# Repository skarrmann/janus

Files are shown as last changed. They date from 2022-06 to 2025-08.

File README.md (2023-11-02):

# Janus Keyboard

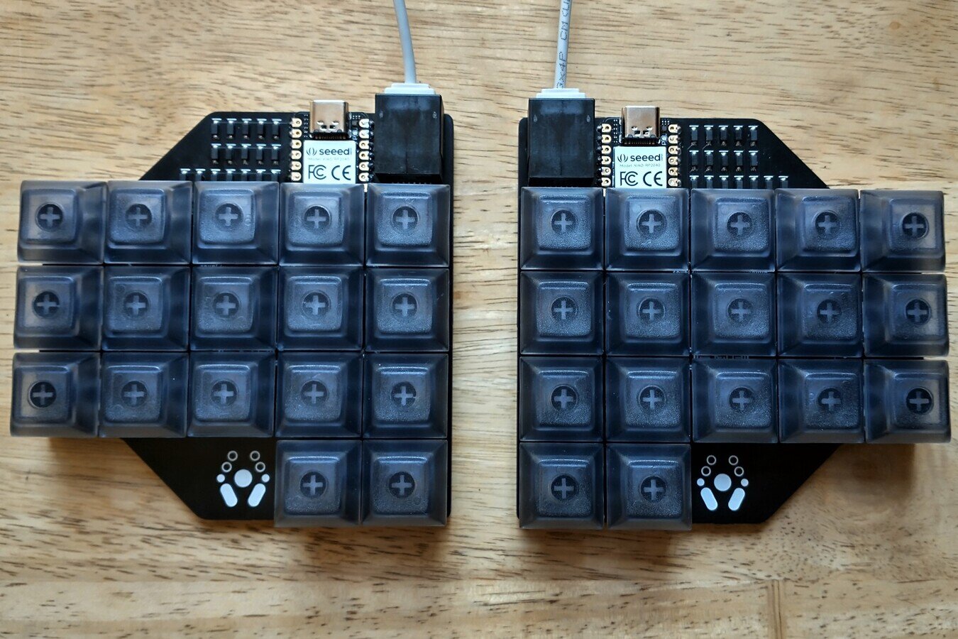
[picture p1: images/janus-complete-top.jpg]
Janus complete build top photo


Janus is a small 34 key split ortholinear keyboard, powered by two Seeed XIAO RP2040 with the keyboards halves connected by an ethernet cable.

The PCB works as both a logical PCB and a bottom plate.

This keyboard is a grid of 1U keys with no special features: no hotswap, no RGB (except those on the XIAO RP2040), no OLED screen, no knobs. It only supports Cherry MX style switches.

## Project structure

* [`gerbers`](gerbers): Gerber files for PCB manufacturing
* [`graphics`](graphics): Source assets for PCB silkscreen
* [`kicad`](kicad): KiCad project files (schematics and PCB designs)
* [`kicad-libraries`](kicad-libraries): KiCad components and footprints
* [`images`](images): Images for project documentation
* [`firmware`](firmware): Firmware files

## PCBs

There is only one PCB design, and 4 copies of this PCB are used to assemble a single keyboard with bottom plates.

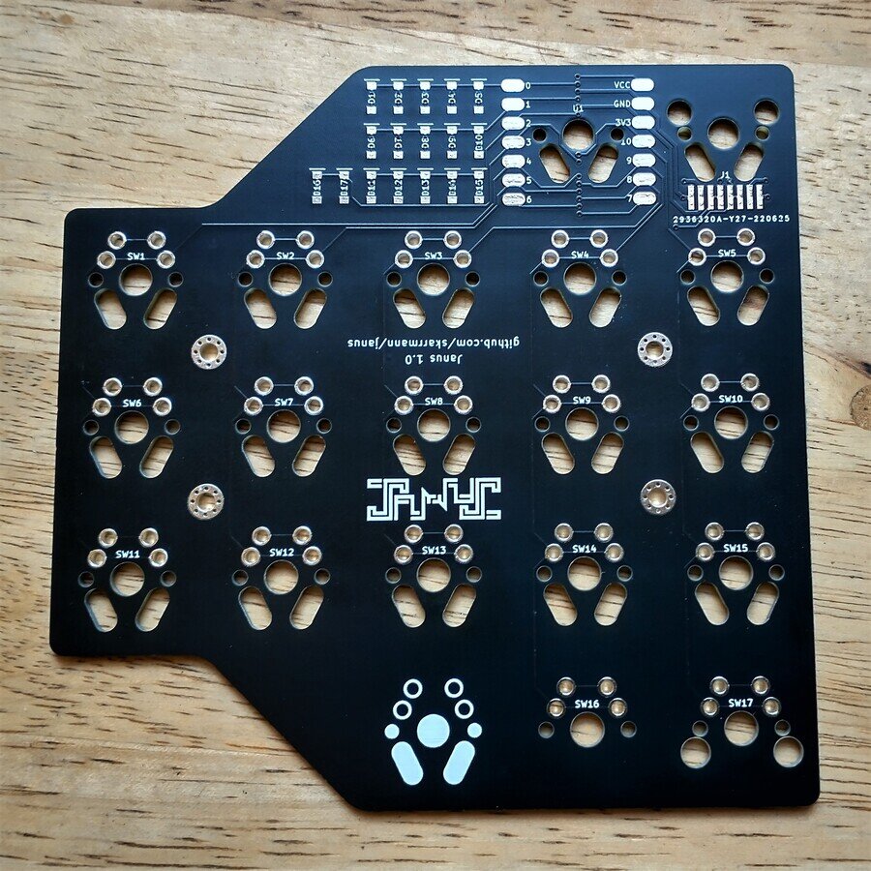
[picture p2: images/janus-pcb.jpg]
Janus one PCB

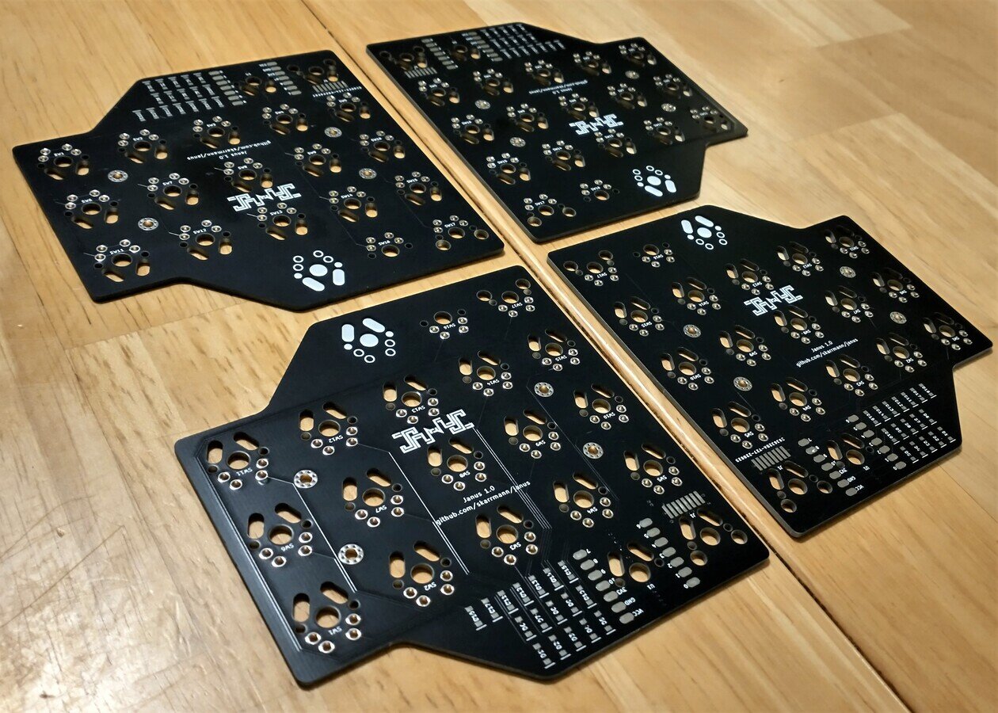
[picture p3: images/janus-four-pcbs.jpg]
Janus four PCBs


The PCB serves as both halves of the split keyboard, as well as bottom plates for those halves.

Flip the board horizontally to get the other keyboard half.

Both keyboard halves have surface-mount solder pads for diodes, microcontroller, and ethernet jack, all on the top side of the PCB.

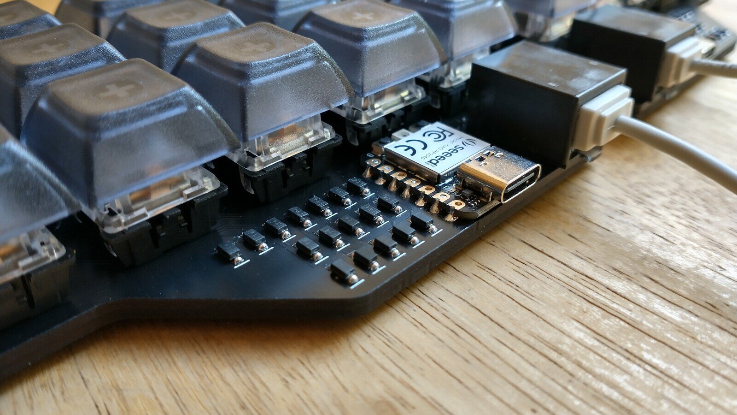
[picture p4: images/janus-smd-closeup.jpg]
Janus SMD components


The PCB is flipped vertically to serve as a bottom plate. The bottom plates are screwed directly to the logical PCB. Note the cutouts on the PCB line up with all the components' through-hole and plastic pins sticking out the bottom of the logical PCB.

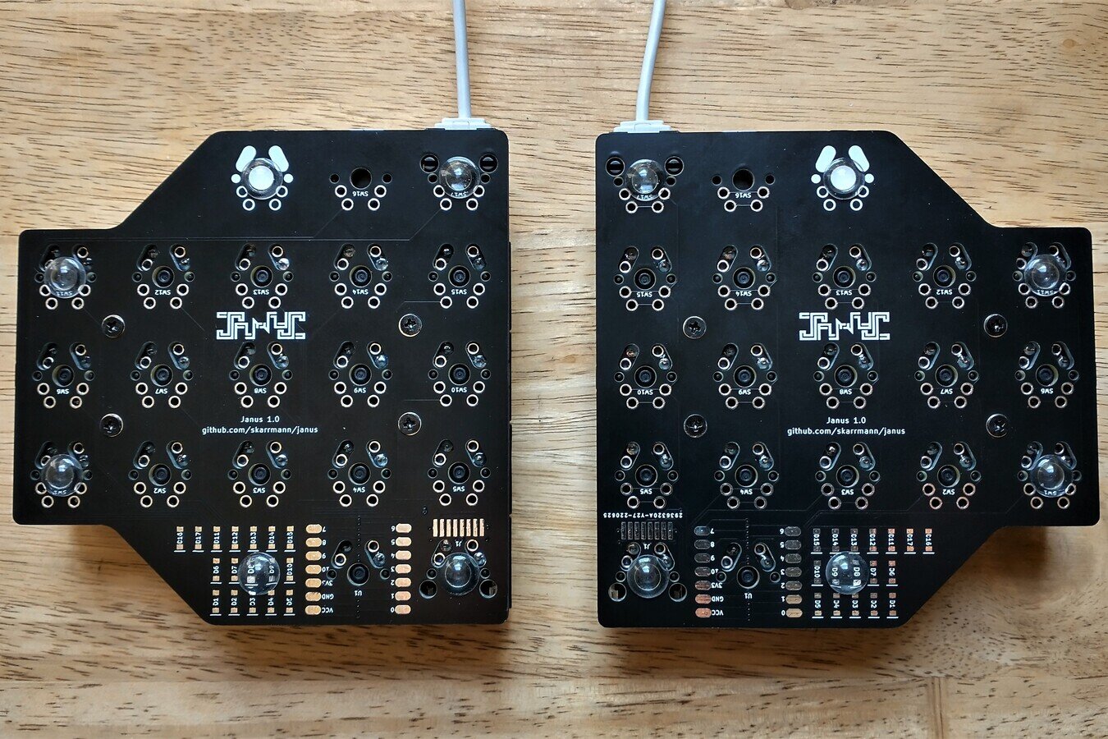
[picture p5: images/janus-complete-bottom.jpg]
Janus complete build bottom photo

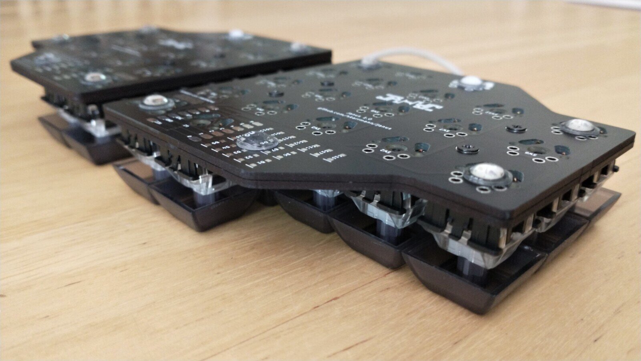
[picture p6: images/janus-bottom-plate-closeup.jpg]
Janus bottom plate closeup


The two halves of the keyboard communicate using full-duplex serial. Note the RX and TX connections are flipped on the top/bottom ethernet jack connections (TX connects to RX and vice-versa).

## Keyboard firmware

* KMK
    * Setup instructions and basic configuration is in this repo: [`firmware/kmk`](firmware/kmk)
* [QMK](https://github.com/qmk/qmk_firmware/tree/master/keyboards/janus)

## Bill of materials

Part | Purpose | Quantity | Notes
---- | ------- | -------- | ---------
PCB  | circuit board | 4 |
Seeed XIAO RP2040 | Microcontroller board | 2 |
Kycon GMX-SMT2-N-88 | connect keyboard halves | 2 | This **exact** connector must be used to fit the board footprint!
1N4148 SOD-123 | Diodes for keyboard row-column matrix | 34 |
Keyswitches |  | 34 | PCB mount (5 pin) switches recommended
Keycaps |  | 34 |
M2 6mm screws | Secure main PCB and plate PCBs | 8 |
M2 nuts | Secure main PCB and plate PCBs | 8 |
2mm tall rubber bumpons | Raise board above desk surface and provide skid resitance | 12 |

You will also need an ethernet patch cable to connect the keyboard halves. Monoprice Micro SlimRun cables are my personal recommendation.

## PCB manufacturing settings

These are the manufacturing settings I used when ordering from JLCPCB:

* **Base Material**: FR4
* **Layers**: 2
* **Dimensions**: (whatever the gerber file specifies)
* **PCB Qty**: 5
* **Different Design**: 1
* **Delivery Format**: Single PCB
* **PCB Thickness**: 1.6
* **PCB Color**: Black
* **Silkscreen**: White
* **Surface Finish**: LeadFree HASL-RoHS
* **Outer Copper Weight**: 1 oz
* **Gold Fingers**: No
* **Confirm Production File**: No
* **Flying Probe Test**: Fully Test
* **Castellated Holes**: No
* **Remove Order Number**: Specify a location

**IMPORTANT:** The PCBs has ["JLCJLCJLCJLC" silkscreen text](https://support.jlcpcb.com/article/28-how-to-remove-order-number-from-your-pcb) underneath the ethernet jack footprint. If you want to remove the order number from the boards or you want to print the PCBs with another manufacturer, then I recommend removing this silkscreen text from the `.kicad_pcb` file, and then regenerate the gerber files.

## Design decisions

The PCB design is in favor of PCB manufacturers' minimum order quantity of 5 and cheaper price at board sizes 100mm x 100mm. Since 4 PCBs are required to build the board with bottom plates, you are only left with one spare PCB.

The Seeed XIAO RP2040 was chosen as the microcontroller because its size works well with the intended layout. It just barely fits within the space of an MX keyswitch. The castellated pads permit surface-mount soldering, which makes the reversible PCB design more practical.

An ethernet connector was chosen to connect the keyboard halves because its connector fits within the space of an MX keyswitch. The Kycon GMX-SMT2-N-88 part was the best fit I could find for this use case. Although only 4 wires are needed for full-duplex serial communication between halves, an 8P8C ethernet jack was chosen over other modular jacks due to better part availability.

## Build tips

* Before starting, check if the PCBs are warped, and bend them to be perfectly flat before soldering.
* Solder the top SMD components first, in order of smallest to largest: diodes, XIAO RP2040, 8P8C ethernet jack
* Before soldering the XIAO RP2040, adhere a piece of electrical tape to its back to prevent potential shorts
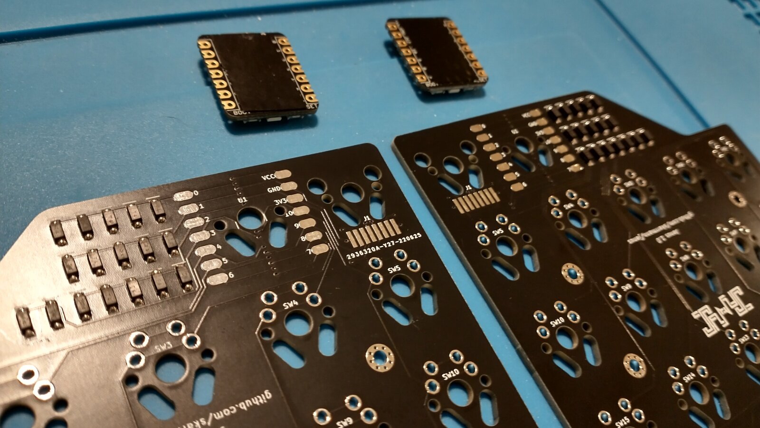
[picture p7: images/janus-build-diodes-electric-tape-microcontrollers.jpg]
Janus build, diodes then XIAO RP2040 with electrical tape
    * 
* Use a piece of heat-resistant tape to align the XIAO RP2040 in place when soldering. Solder the opposing edge pads, and ensure the component is straight and flat.
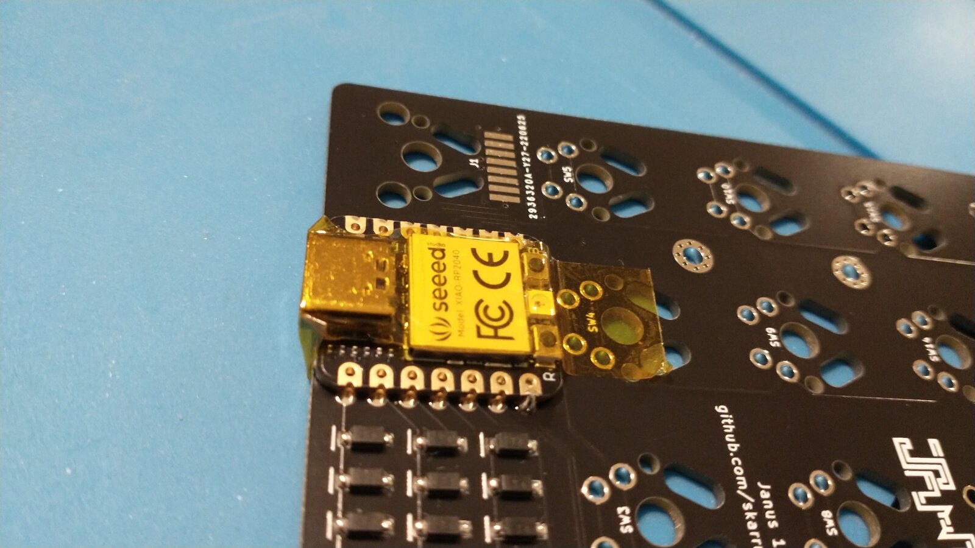
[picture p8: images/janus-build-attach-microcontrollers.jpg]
Janus build, Kapton tape on XIAO RP2040
    * 
* Solder the switches last!
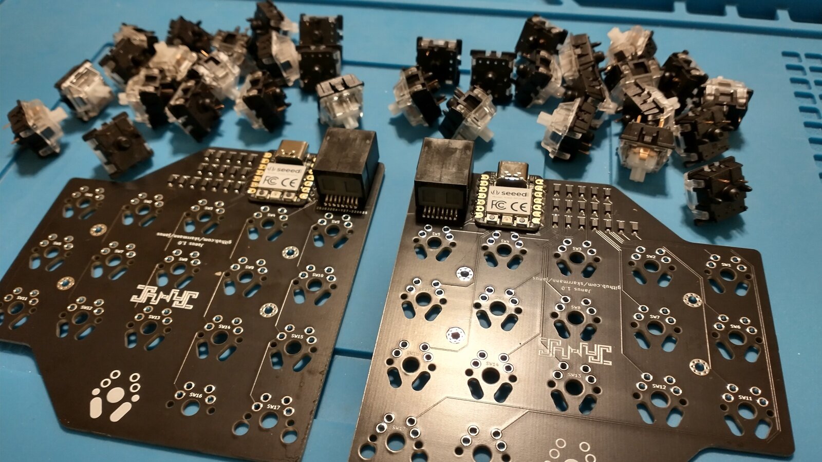
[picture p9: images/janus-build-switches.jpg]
Janus build, switches
    * 
* Attaching the bottom plates with M2 screws and nuts takes patience and a steady hand. If it's too annoying, use double-sided tape instead!

## KiCad project notes

Separate symbols and footprints are defined for the bottom plate cutouts (both for for MX switches and the 8P8C ethernet jack). No special code nor plugins are used here; these cutouts are manually positioned in the PCB design.

## Revision history

* **Janus 1.0** (2022-06-24)
    * Initial PCB design

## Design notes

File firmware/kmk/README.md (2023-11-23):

# Janus KMK Firmware

## Installation instructions

Apply these steps on each XIAO RP2040:

1. Install CircuitPython:
    * https://circuitpython.org/board/seeeduino_xiao_rp2040/
2. Following [KMK's split keyboard drive name convention](https://github.com/KMKfw/kmk_firmware/blob/master/docs/en/split_keyboards.md#drive-names), rename the `CIRCUITPY` drive to indicate whether it's the left or right side:
    * Left: `JANUS_L`
    * Right: `JANUS_R`
2. Copy KMK firmware files:
    * https://github.com/KMKfw/kmk_firmware/blob/master/docs/en/Getting_Started.md
3. Copy the custom files:
    * [`kb.py`](kb.py)
    * [`main.py`](main.py)
    * [`oneshot_mod.py`](oneshot_mod.py)

Now customize the layout and features in [`main.py`](main.py) file, and save the updates on your board.

## Default keymap

View the [Janus default keymap on Keyboard Layout Editor](http://www.keyboard-layout-editor.com/#/gists/5144ea6a6c998df5f502f9240068de80)

This default keymap is inspired by [Callum's QMK keymap](https://github.com/qmk/qmk_firmware/tree/master/users/callum), with the following differences:

* Mods are moved to the bottom row on every layer, and are mirrored on both sides.
* Symbol layer only contains non-shifted symbol keys.
* General differences in key positions.

Both layouts use similar oneshot key implementations.

## Custom oneshot module

As part of the oneshot module's setup, the following two methods should be called:

* `set_ignore_keys(ignore_keys)`: Specify a list of keys which are not treated as oneshot interrupt keys

Oneshot keys behave as follows:

* When a oneshot key is pressed:
    * Set oneshot status as "active"
    * Send a key press event for its corresponding key
* When a oneshot key is released:
    * If oneshot status is "active", then set this oneshot key's status as "queued"
    * If oneshot status is not "active", send a key release event for its corresponding key
* When an interrupt key (i.e., not a oneshot key and not an ignored key) is pressed:
    * Set oneshot status as "inactive"
    * For every oneshot key with status "queued", send key release event for their corresponding key
    * Clear all oneshot key statuses

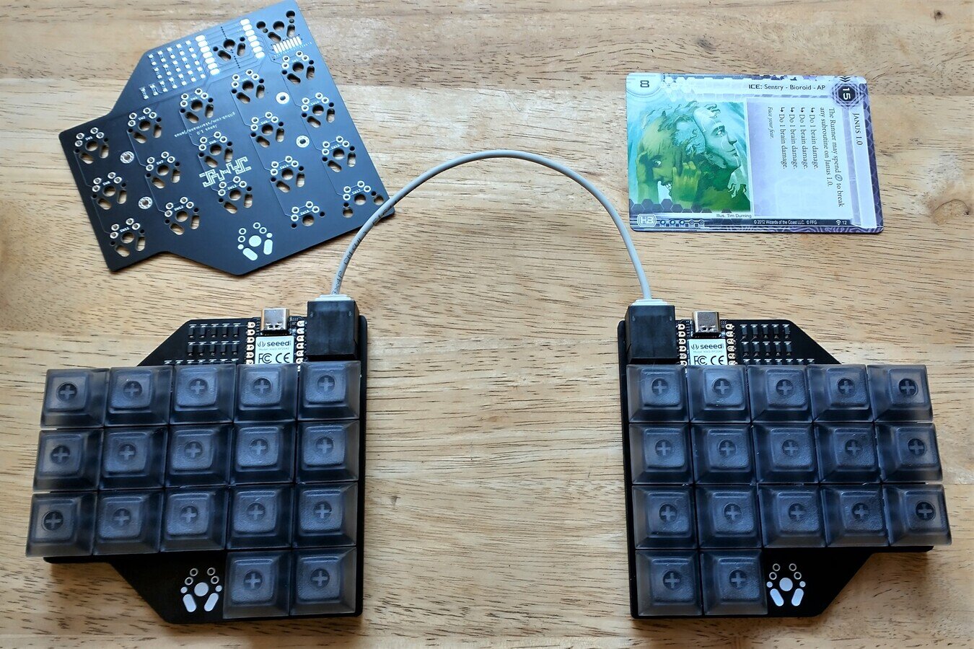
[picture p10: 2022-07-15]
images/janus-with-janus.jpg

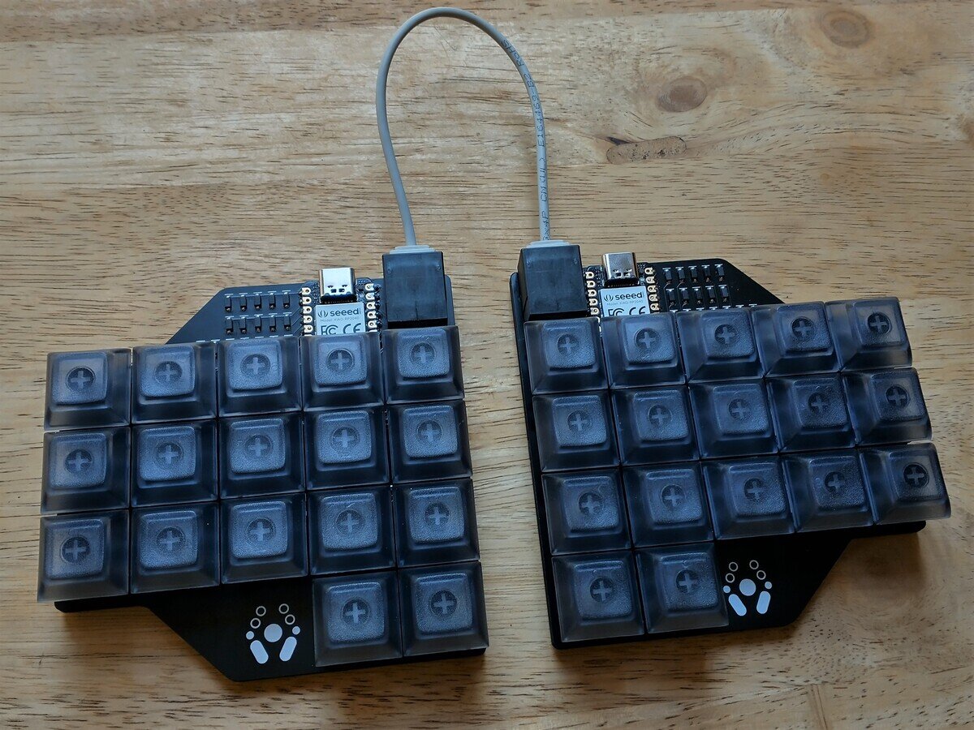
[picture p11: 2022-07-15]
images/janus-complete-with-cable-in-view.jpg

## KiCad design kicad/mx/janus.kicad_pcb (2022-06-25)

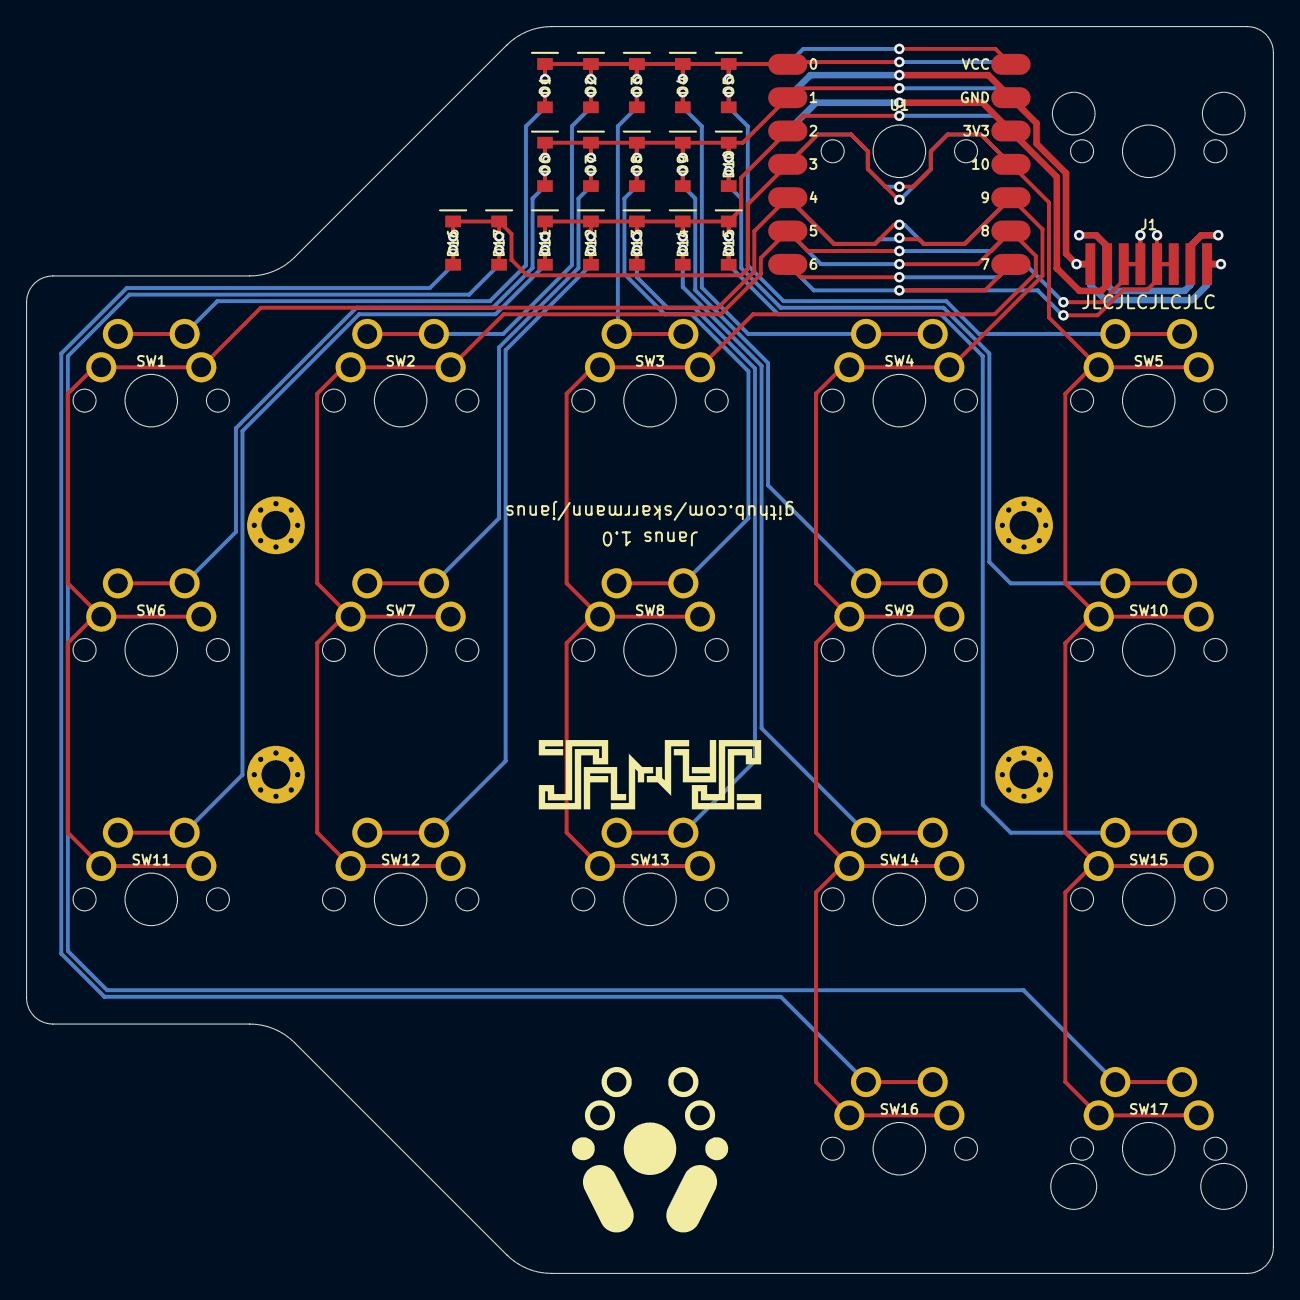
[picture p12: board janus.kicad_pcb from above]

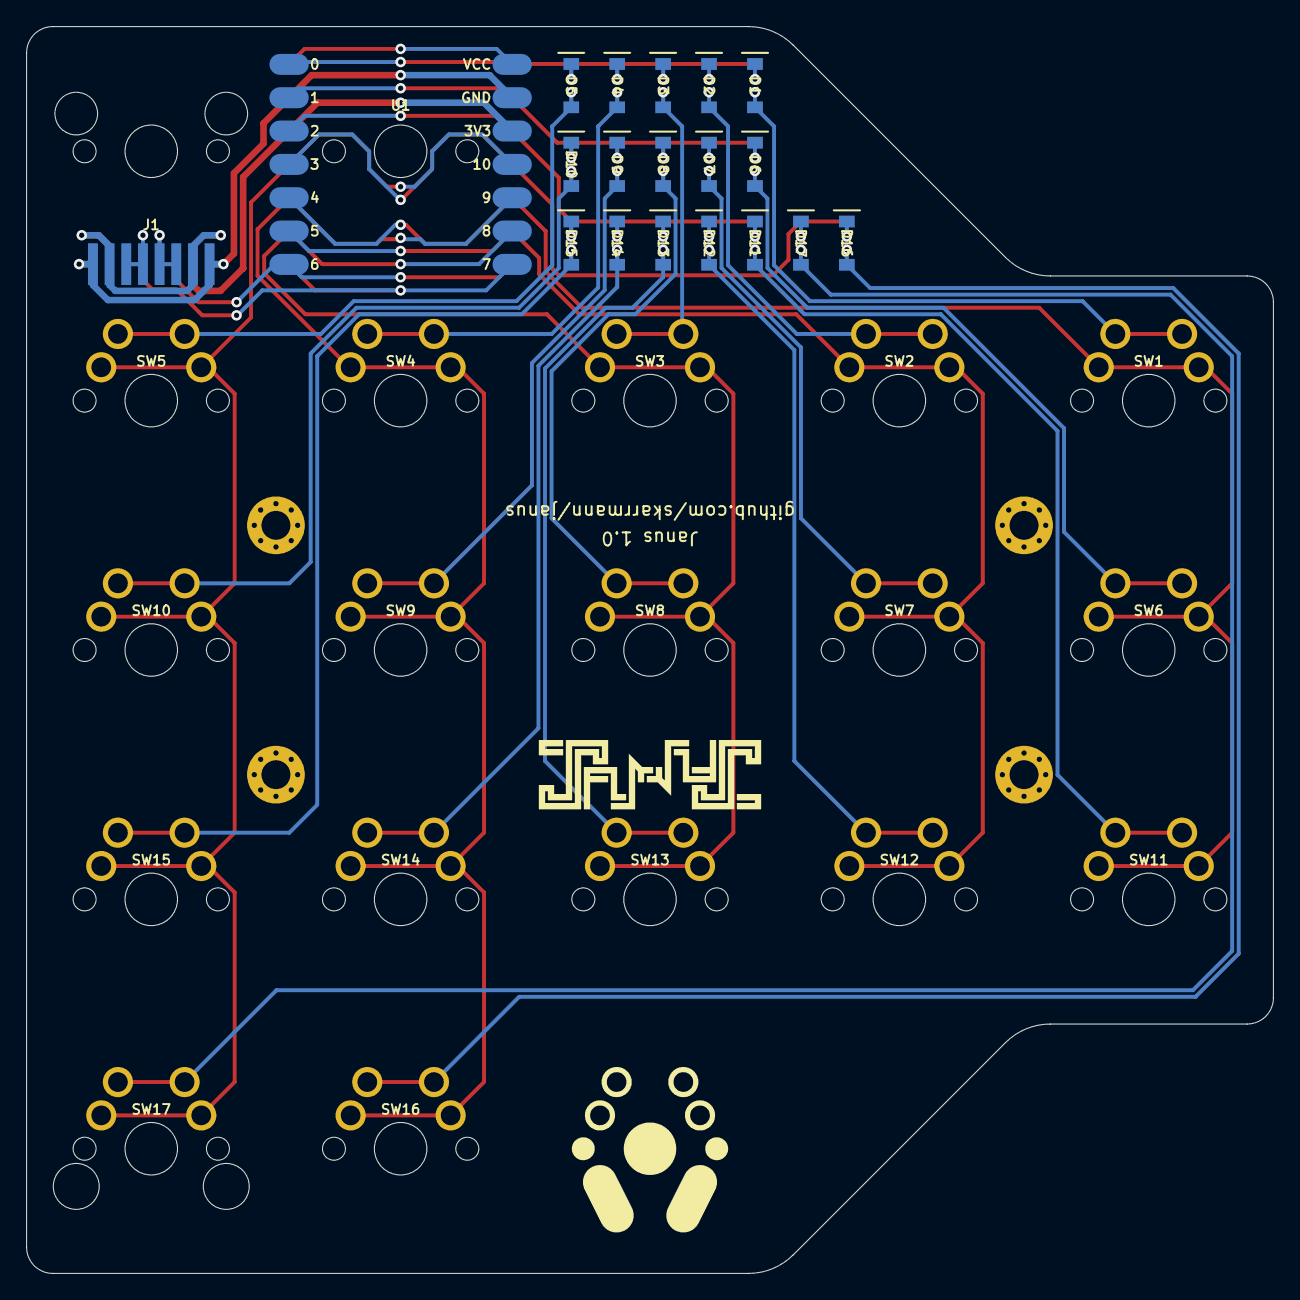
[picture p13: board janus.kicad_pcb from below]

Board: 2 copper layers, 95.0 x 95.0 mm, 62 parts (2 on the bottom side), 30 nets.

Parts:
CUTOUT1, CUTOUT2: Cutout-MX_Full; Cutout_SW_MX_Full
CUTOUT3, CUTOUT4, CUTOUT5, CUTOUT6, CUTOUT7, CUTOUT8, CUTOUT9, CUTOUT10, CUTOUT11, CUTOUT12, CUTOUT13, CUTOUT15, CUTOUT16, CUTOUT17: Cutout-MX; Cutout_SW_MX_Pads
CUTOUT14: Cutout; Cutout_SW_MX_Pads
CUTOUT18: Cutout-8P8C; Cutout_8P8C_SMT
D1, D2, D3, D4, D5, D6, D7, D8, D9, D10, D11, D12, D13, D14, D15, D16, D17: D; D_SOD-123_Reversible
H1, H2, H3, H4: Hole_Pad; Mount_M2
J1: 8P8C Double Sided; 8P8C_SMT_Double_Sided
LOGO1: Logo-Bottom; Logo_Janus
LOGO2: Logo-Top; Logo_Janus
LOGO3: Footprint-Top; Logo_Janus_Footprint
LOGO4: Footprint-Bottom; Logo_Janus_Footprint
SW1, SW2, SW3, SW4, SW5, SW6, SW7, SW8, SW9, SW10, SW11, SW12, SW13, SW14, SW15, SW16, SW17: SW_Push; SW_MX_Reversible
U1: XIAO RP2040; XIAO-RP2040_Reversible

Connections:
COL1: SW1.1, SW6.1, SW11.1, U1.5 (4)
COL2: SW2.1, SW7.1, SW12.1, U1.6 (5)
COL3: SW3.1, SW8.1, SW13.1, U1.9 (8)
COL4: SW4.1, SW9.1, SW14.1, SW16.1, U1.10 (9)
COL5: SW5.1, SW10.1, SW15.1, SW17.1, U1.11 (10)
GND: J1.1, J1.8, J1.9, J1.16, U1.13 (GND)
unnamed: D1.2 (A), SW1.2
unnamed: D2.2 (A), SW2.2
unnamed: D3.2 (A), SW3.2
unnamed: D4.2 (A), SW4.2
unnamed: D5.2 (A), SW5.2
unnamed: D6.2 (A), SW6.2
unnamed: D7.2 (A), SW7.2
unnamed: D8.2 (A), SW8.2
unnamed: D9.2 (A), SW9.2
unnamed: D10.2 (A), SW10.2
unnamed: D11.2 (A), SW11.2
unnamed: D12.2 (A), SW12.2
unnamed: D13.2 (A), SW13.2
unnamed: D14.2 (A), SW14.2
unnamed: D15.2 (A), SW15.2
unnamed: D16.2 (A), SW16.2
unnamed: D17.2 (A), SW17.2
ROW1: D1.1 (K), D2.1 (K), D3.1 (K), D4.1 (K), D5.1 (K), U1.1 (0)
ROW2: D6.1 (K), D7.1 (K), D8.1 (K), D9.1 (K), D10.1 (K), U1.2 (1)
ROW3: D11.1 (K), D12.1 (K), D13.1 (K), D14.1 (K), D15.1 (K), U1.3 (2)
ROW4: D16.1 (K), D17.1 (K), U1.4 (3)
RX: J1.3, J1.4, J1.13, J1.14, U1.8 (7)
TX: J1.5, J1.6, J1.11, J1.12, U1.7 (6)
VCC: J1.2, J1.7, J1.10, J1.15, U1.12 (3V3)

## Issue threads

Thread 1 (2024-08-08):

left or right side logic ?

flatmax, 2024-08-08:
Hi there, I love your keyboard.

I'm trying to workout how the firmware knows whether the board is the left or right side board ?
I can't see it in any of the qmk files : https://github.com/qmk/qmk_firmware/tree/master/keyboards/janus

skarrmann, 2024-08-08:
Hi @flatmax!

Thank you for your inquiry, and I'm happy you like Janus! It has been a while since I looked at the QMK firmware configuration.

I will take a look tomorrow evening and get back to you around then.

Regards,
Steve

skarrmann, 2024-08-10:
The Janus QMK firmware configuration did not have way to detect handedness. So if you plug the USB cable into the left side, all is well. But if you plug the USB cable in the right side, the layout would be mirrored!

By the PCB's design, I do not believe there is a way of detecting whether the left or right side is plugged in.

So to fix this limitation and allow plugging in either side of the keyboard, I just added support for (detecting handedness by EEPROM)[https://github.com/qmk/qmk_firmware/pull/24261].

Here is the pull request in the QMK firmware repository: https://github.com/qmk/qmk_firmware/pull/24261

Please let me know if this solution addresses your issue!

skarrmann, 2024-09-10:
I am closing this issue since the solution supports either left or right side logic in QMK.

Please let me know if you need any assistance, thank you!

Closed 2024-09-10.

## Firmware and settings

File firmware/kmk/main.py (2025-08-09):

from kb import KMKKeyboard
from kmk.keys import KC
from kmk.modules.split import Split
from kmk.modules.layers import Layers
from kmk.extensions.media_keys import MediaKeys
from kmk.extensions.international import International
from oneshot import OneShot


keyboard = KMKKeyboard()

split = Split(
    data_pin = keyboard.data_pin,
    data_pin2 = keyboard.data_pin2,
    uart_flip = keyboard.uart_flip,
)
layers_ext = Layers()
oneshot_ext = OneShot()
media_keys = MediaKeys()
international = International()

keyboard.modules = [split, layers_ext, oneshot_ext]
keyboard.extensions = [media_keys, international]

SYM = KC.MO(1)
NAV = KC.MO(2)
FUN = KC.MO(3)

OS_LCTL = KC.OS(KC.LCTL)
OS_LSFT = KC.OS(KC.LSFT)
OS_LALT = KC.OS(KC.LALT)
OS_LGUI = KC.OS(KC.LGUI)
OS_RCTL = KC.OS(KC.RCTL)
OS_RSFT = KC.OS(KC.RSFT)
OS_RALT = KC.OS(KC.RALT)
OS_RGUI = KC.OS(KC.RGUI)

oneshot_ext.set_ignore_keys([SYM, NAV, FUN])

keyboard.keymap = [
    [   # Default
        KC.Q,    KC.W,    KC.F,    KC.P,    KC.G,    KC.J,    KC.L,    KC.U,    KC.Y,    KC.QUOT,
        KC.A,    KC.R,    KC.S,    KC.T,    KC.D,    KC.H,    KC.N,    KC.E,    KC.I,    KC.O,
        KC.Z,    KC.X,    KC.C,    KC.V,    KC.B,    KC.K,    KC.M,    KC.COMM, KC.DOT,  KC.SLSH,
                                   NAV,     KC.LSFT, KC.SPC,  SYM
    ],
    [   # Symbol
        KC.SCLN, KC.LBRC, KC.RBRC, KC.N5,   KC.NO,   KC.NO,   KC.N6,   KC.MINS, KC.EQL,  KC.GRV,
        KC.N1,   KC.N2,   KC.N3,   KC.N4,   KC.BSLS, KC.NO,   KC.N7,   KC.N8,   KC.N9,   KC.N0,
        OS_LGUI, OS_LALT, OS_LSFT, OS_LCTL, KC.NO,   KC.NO,   OS_RCTL, OS_RSFT, OS_RALT, OS_RGUI,
                                   FUN,     KC.TRNS, KC.TRNS, KC.TRNS
    ],
    [   # Navigation
        KC.PSCR, KC.INS,  KC.APP,  KC.DEL,  KC.NO,   KC.NO,   KC.HOME, KC.PGDN, KC.PGUP, KC.END,
        KC.ESC,  KC.TAB,  KC.ENT,  KC.BSPC, KC.NO,   KC.PAUS, KC.LEFT, KC.DOWN, KC.UP,   KC.RGHT,
        OS_LGUI, OS_LALT, OS_LSFT, OS_LCTL, KC.NO,   KC.NO,   OS_RCTL, OS_RSFT, OS_RALT, OS_RGUI,
                                   KC.TRNS, KC.TRNS, KC.TRNS, FUN
    ],
    [   # Function
        KC.F1,   KC.F2,   KC.F3,   KC.F4,   KC.NO,   KC.SLCK, KC.MPLY, KC.MPRV, KC.MNXT, KC.BRIU,
        KC.F5,   KC.F6,   KC.F7,   KC.F8,   KC.NO,   KC.CLCK, KC.MUTE, KC.VOLD, KC.VOLU, KC.BRID,
        KC.F9,   KC.F10,  KC.F11,  KC.F12,  KC.NO,   KC.NLCK, OS_RCTL, OS_RSFT, OS_RALT, OS_RGUI,
                                   KC.TRNS, KC.TRNS, KC.TRNS, KC.TRNS
    ]
]

if __name__ == '__main__':
    keyboard.go()

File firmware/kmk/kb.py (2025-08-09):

import board
from kmk.kmk_keyboard import KMKKeyboard as _KMKKeyboard
from kmk.scanners import DiodeOrientation


class KMKKeyboard(_KMKKeyboard):
    def __init__(self):
        super().__init__()
        self.col_pins = (board.D4, board.D5, board.D8, board.D9, board.D10)
        self.row_pins = (board.D0, board.D1, board.D2, board.D3)
        self.diode_orientation = DiodeOrientation.COLUMNS
        self.data_pin = board.D7
        self.data_pin2 = board.D6
        self.uart_flip = False

        self.coord_mapping = [
            0,  1,  2,  3,  4, 24, 23, 22, 21, 20,
            5,  6,  7,  8,  9, 29, 28, 27, 26, 25,
            10, 11, 12, 13, 14, 34, 33, 32, 31, 30,
                        18, 19, 39, 38
        ]

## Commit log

2022-06-25 Center silkscreen logo
    [janus.kicad_pcb]
2022-07-17 Update KMK firmware with proper board definition and usable layout
2022-07-22 Update BOM vendor links
